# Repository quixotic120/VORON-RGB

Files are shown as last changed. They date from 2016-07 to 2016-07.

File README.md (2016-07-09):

# VORON-RGB

a fork to collect my changes to the Voron design. WIP at this point and untested but the changes are somewhat minor

##changes

increased volume - 300x300x300 (ish, lose some z axis as described below)

_bed supports_

modular steps updated to support anti-backlash delrin leadscrew nuts. For modded parts I've posted 123dx files and STLs. Also have an untested modification of the non-modular one if that's your thing.

_electronics_

currently using RADDS 1.5 w/ silentstepsticks but hopefully will be using my version of [RAMPS-FD](https://github.com/quixotic120/bobc_hardware/tree/master/RAMPS-FD)soon (once the kinks are worked out, on my git). Have modded the RADDS a bit with better headers and a converter for the RRD-graphic LCD

_color mixing hotend support_

added mount for the diamond hotend, different extruder design and 3 extruders for color mixing purposes (hopefully 5 soon for full color!). Kept it in line with the modular format used so it should be fairly easy to swap in a different hotend (I have an extra e3dv6-lite for this). 2 reasons: 1 being the diamond brings a lot of complexity so if it's not needed I prefer to avoid it and 2 being that the diamond is HUGE and you lose a bit of z axis as a result

extruder being used is [located here](https://github.com/quixotic120/printer-mods/tree/master/bowden)

_software_

using repetier instead of marlin for color mixing and due board support - untested but configuration should work?

_other_

using the excellent bed knobs by [bhstibal](http://www.thingiverse.com/thing:1645108)

considering using [hall effect endstops](https://github.com/quixotic120/hall-o)

using dc42s diff IR endstop instead of the inductive ones which kind of suck IMO. if you use the diff IR it is beneficial to paint the PEI black with high temp paint (like the kind of grills or engines)

using e3d pt-100 for hotends, using the e3d cartridge thermistor on the bed

adding a thermal fuse to the bed

##TODO:
Printer enclosure

RADDS enclosure - would like an enclosure that could hold RADDS, due, a pi zero for octoprint, and a header for powering accessories. Ideally in the style of the voron RAMPS enclosure

Camera mount

Filament Jam sensor and the possible modifications needed to firmware to make such a thing work with multiple filament extruders

#__original readme__

# VORON  


Reddit: [/r/voroncorexy](https://www.reddit.com/r/voroncorexy/)

Firmware, plans, and parts for VORON RepRap printer

## Updates:  

_Apr 30, 2016:_  
REV C Parts are pushed (STL and STEP). Parts included in this release:  
- Improved Bed Carriage  
- V1-to-REV C leadscrew adapter (for those who already printed v1)  
- Improved RAMPs Case  
- Improved Power Box (and mirror of v1 as default)  

_Apr 22, 2016:_  
Massive update to the manual. All motion system are done. Next is filamnt systems, and wiring. 
Also, added a BSP adapter for E3D Titan.

In other news, we have a sub-reddit now! Link at the top of the page.

_Apr 19, 2016:_  
Updated the BOM to reflect the REV B components. Link updated.

_Apr 17, 2016:_  
REV B Carriage is up. Belt tensioning every each way. I've cleaned up the folder to get rid of some older stuff nobody should be using now anyway.  
Description of changes here: http://imgur.com/a/EneHq

_Apr 15, 2016:_  
Quick update: The manual stalled out due to work on REV B of the X Carriage. At I started writing down the process, I became convinced belt tensioning is a thing that needs to happen. So I'm bringing back a version of what I had on the prototype printer. New carriage will also have a better way to mount a single E3D hot end, so you don't have to take apart X Carriage to remove it.

There are a few other special projects in the works, one of them involving E3D Titan ;)  

REV B will be going up tomorrow after I have a chance to put some more QA time on it.  

_Apr  4, 2016:_  
Updated BOM to reflect some changes discussed on GitHub. Big thanks to codexmas for QA work. Checked in a PDF version of the BOM. Manual is getting closer to being finished.

_Mar 22, 2016:_  
REV A STLs are published. Updated to the X Carriage to house a blower fan. Also updated the BOM to reflect the new configuration.

_Mar 8, 2016:_  
ver1.0 of the STLs has been released. Happy printing.

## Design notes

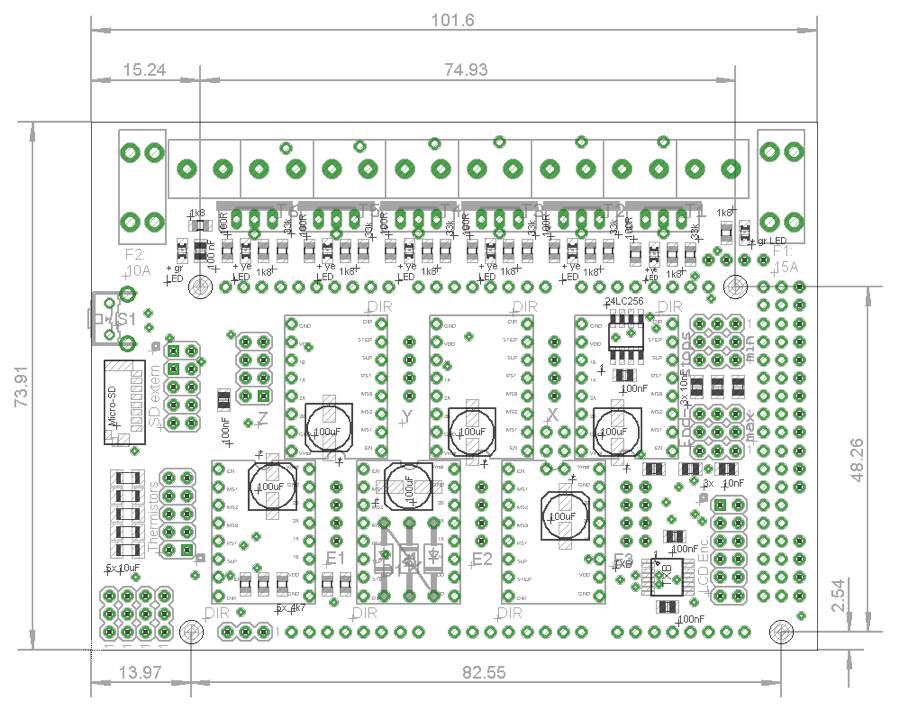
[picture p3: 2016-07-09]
RGB/WIP/RADDS_Case/Picture1.png

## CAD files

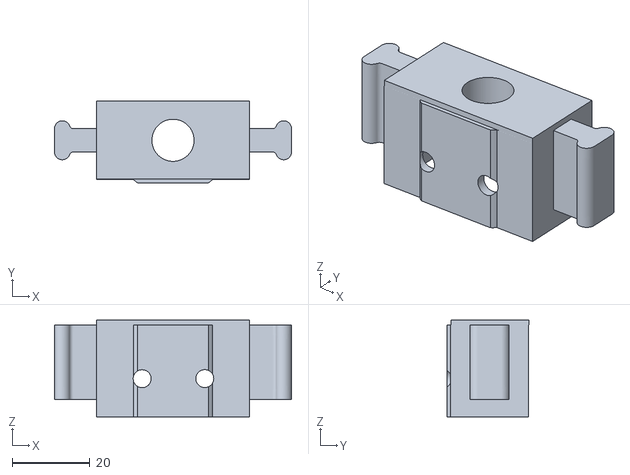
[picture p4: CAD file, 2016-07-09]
RGB/STL/BED C.stl
60.8 x 20.9 x 24.8

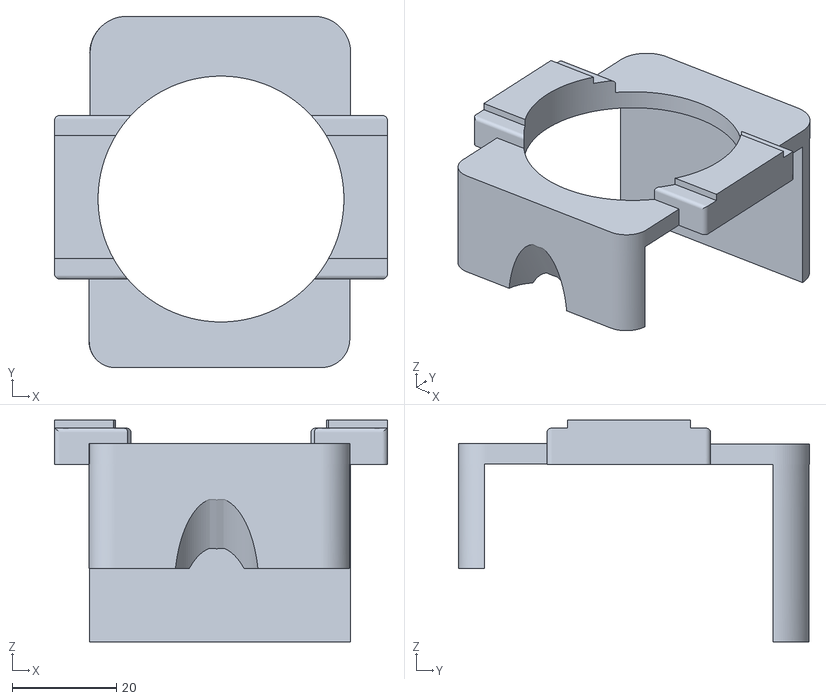
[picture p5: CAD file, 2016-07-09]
RGB/STL/x carriage lower.stl
63.9 x 67.4 x 42.5

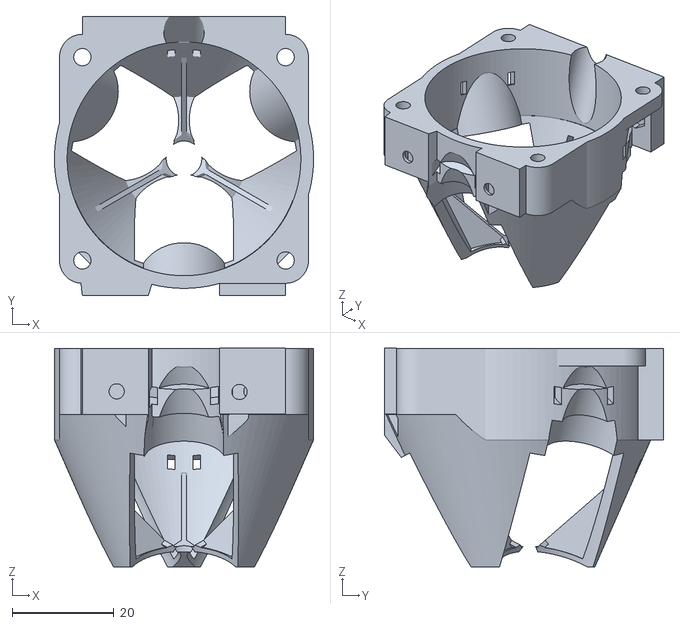
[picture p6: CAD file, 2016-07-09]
RGB/STL/diamond mount.stl
51.0 x 54.9 x 43.1

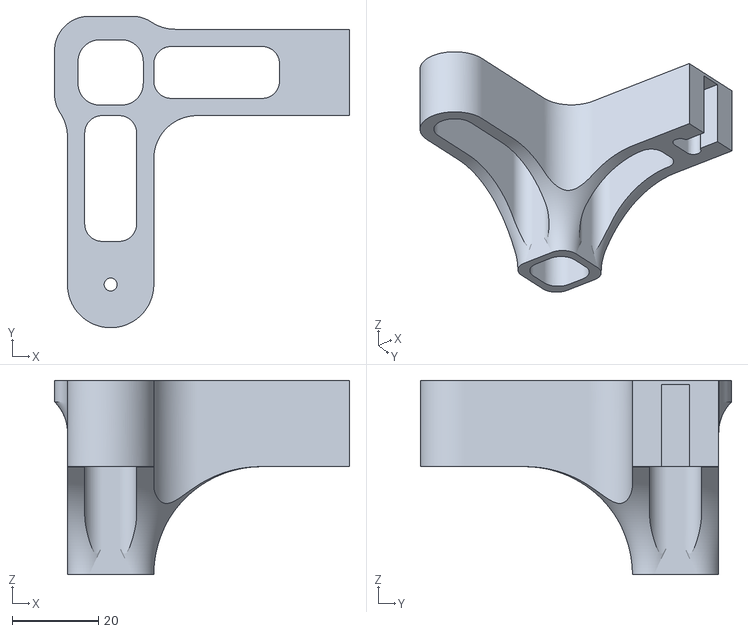
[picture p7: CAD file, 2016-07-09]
RGB/STL/BEDR.stl
68.3 x 72.1 x 45.0

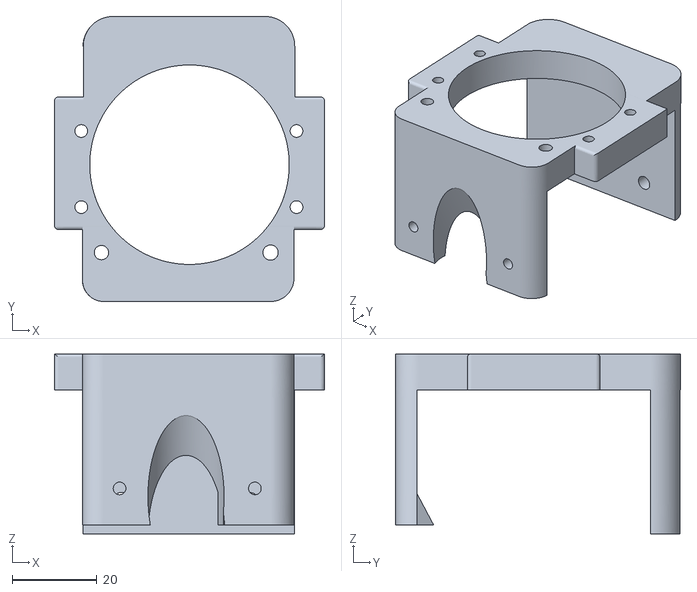
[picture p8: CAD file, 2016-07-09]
RGB/STL/x lower.stl
63.9 x 67.4 x 42.5

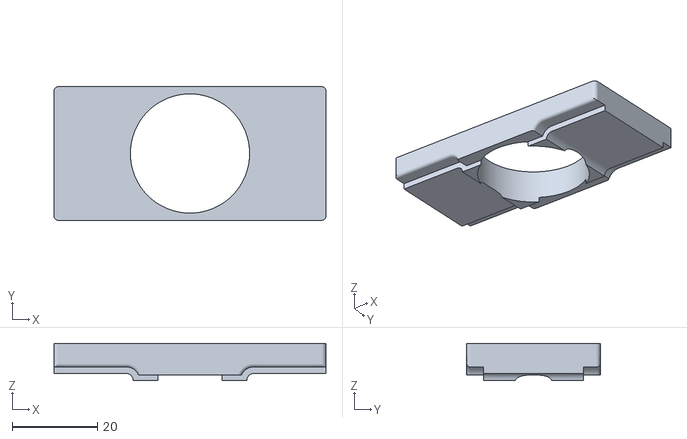
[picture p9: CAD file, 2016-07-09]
RGB/STL/x carriage upper.stl
63.9 x 31.4 x 8.70

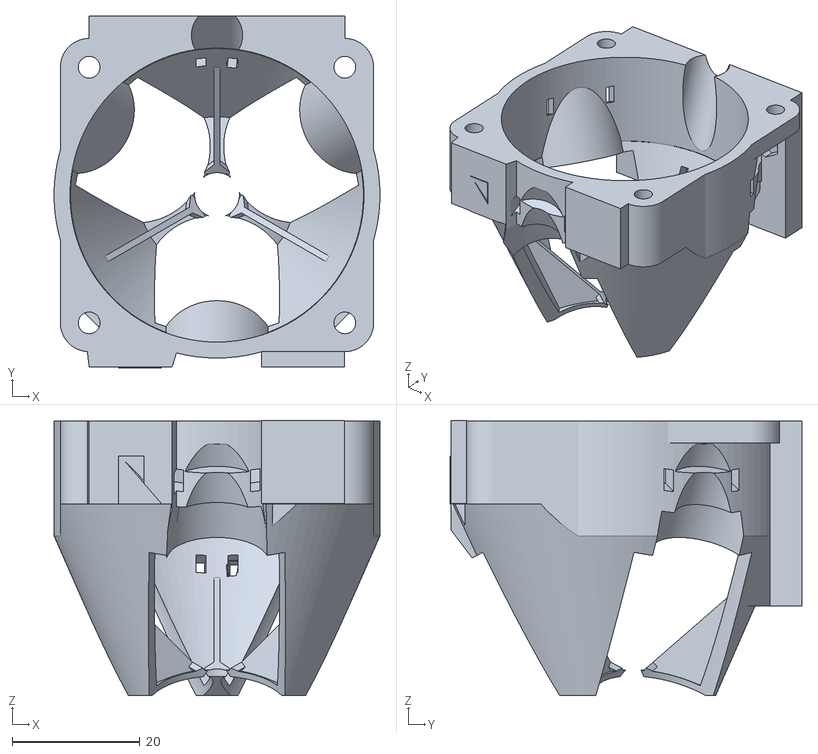
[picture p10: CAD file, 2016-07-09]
RGB/STL/updated diamond mount.stl
51.0 x 55.0 x 43.1

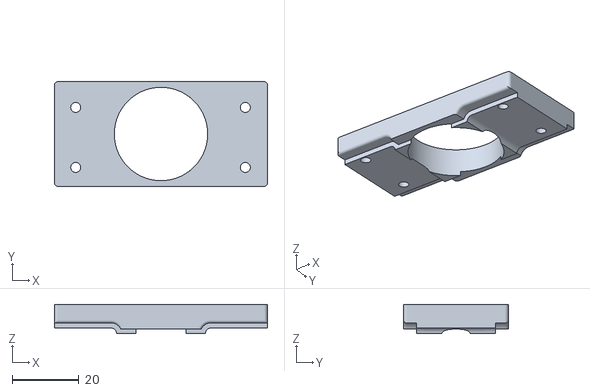
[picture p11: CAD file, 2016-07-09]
RGB/STL/x mount top.stl
63.9 x 31.4 x 8.70

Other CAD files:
RGB/STL/diamond w mount.stl
RGB/STL/BED L.stl

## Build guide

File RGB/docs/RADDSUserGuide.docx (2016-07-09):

# Wiring and configuration

## 1.1 Wiring diagram

### 1.1.1 Stepper drivers and motors

#### 1.1.1.1 Stepper motor

Before you can connect the stepper motor to RADDS or SilentStep , you need some information on the stepper motor you have.

Look at your motor, find its part number. Then Google it. Try to find a schematic or a data-sheet that will indicate which wire goes to which pole. Note the colors that correspond to each coil.

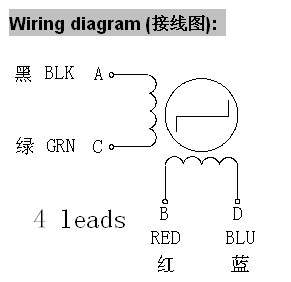
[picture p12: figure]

Wiring diagram for Wantai 42BYGHW609 stepper motor (from www.wantamotor.com).

If you can`t find the motor`s part number, you can use another method to find the motor`s pole pairs.
When two wires for a pole (A +C or B+D) touch together it makes a closed circuit for that pole and it gets harder to turn the stepper motor.

1. Try to turn the motor when no cables touch together – it should turn freely.
2. Touch two of the cables together – if the motor gets harder to turn, you have found a pole pair. If not, try to touch two other cables together until the motor gets harder to move.
3. When you have two cables together that makes it harder to turn the motor, you have found a pole pair.

Note the colors for each pole pair (Pair 1 = 1A +1B, Pair 2 = 2A+2B)



On the Wantai 42BYGHw609 the colors are:
1A = Black
1B = Green
2A = Blue
2B = Red

It does not matter if you swap the pole pairs. If the motor turns the wrong way, you can reverse it in the configuration file.

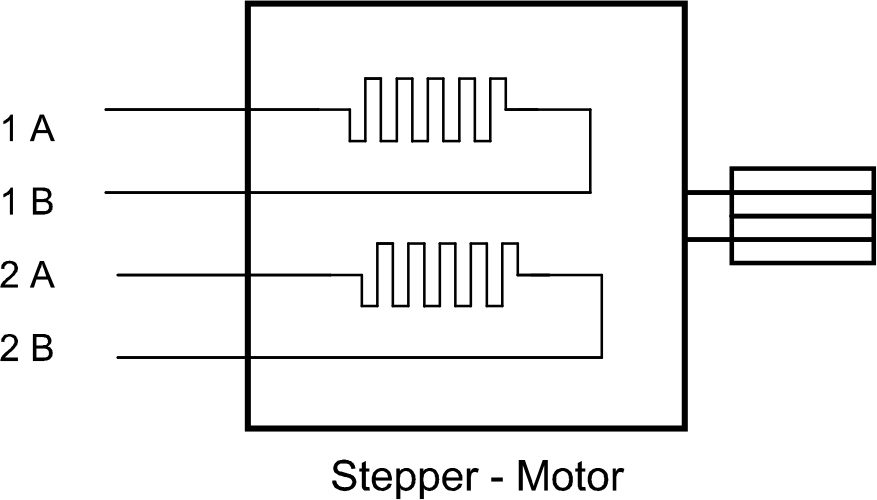
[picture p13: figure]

#### 1.1.1.2 Micro stepping

A stepper motor always has a fixed number of steps. Microstepping is a way of increasing the number of steps by sending a sine/cosine waveform to the coils inside the stepper motor. In most cases, micro stepping allows stepper motors to run smoother and more accurately.

Microstepping between pole-positions is made with lower torque than with full-stepping, but has much lower tendency for mechanical oscillation around the step-positions and you can drive with much higher frequencies.

If your motors are near to mechanical limitations and you have high friction or dynamics, microsteps do not give you much more accuracy over half-stepping. When your motors are 'overpowered' and/or you do not have much friction, then microstepping can give you much higher accuracy over half-stepping. You can transfer the higher positioning accuracy to moving accuracy too

Source: http://www.reprap.org/wiki/Stepper_motor#Micro_stepping

If you want to alter the micro stepping value on one or more axis, you have to set the correct value. When using SilentStep , you set it using the dipswitches on the SilentStep and modify the values in the configuration.h file

Each time you increase the stepping one level (sample: from 1/16 to 1/32) you have to multiply the steps per unit value by two.

Sample – You are using 1/16 steps per unit and the value is 80 and want to use 1/32 steps per unit.

If your steps per unit value is 80, you have to multiply 80 by two (2x80).

New steps per unit value = 160

// #define DEFAULT_AXIS_STEPS_PER_UNIT {78.7402,78.7402,200.0*8/3,760*1.1} // default steps per unit for Ultimaker

//#define DEFAULT_AXIS_STEPS_PER_UNIT {80,80,2560,107} // default steps per unit for OrdBot 1/16

#define DEFAULT_AXIS_STEPS_PER_UNIT {160,160,5120,214} // default steps per unit for OrdBot 1/32

This code sample is from Marlin.

The “default steps per unit for OrdBot 1/16” gives you the values for 1/16 micro stepping.

80, 80, 2560, 107
X-Axis = 80 steps/mm
Y-Axis = 80 steps/mm
Z-Axis = 2560 steps/mm
Extruder motor = 107 steps/mm (this is the setting for Bulldog Lite Extruder. You have to find the correct setting for the extruder you use)

In the next code line, you find “default steps per unit for OrdBot 1/32”. This is the settings when 1/32 microstepping are used. Here all values have been multiplied with two.

#### 1.1.1.3 Set the micro stepping mode on RADDS 1.1

When you use stepper drivers like the A4988, DRV8825 (NOT WHEN USING EXTERNAL DRIVERS LIKE SILENTSTEP ) you have to set the micro stepping mode by cutting or connecting the traces on the back of the RADDS board.

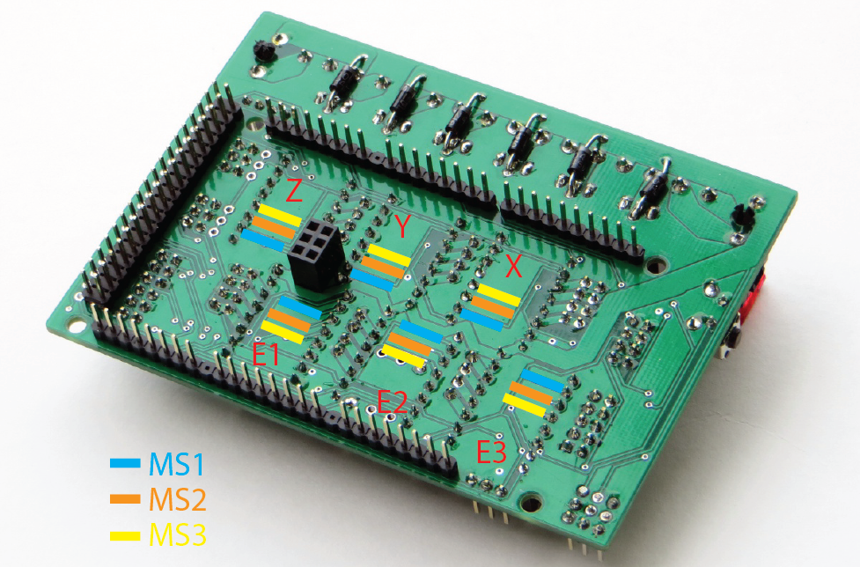
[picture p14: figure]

A4988 | | | DRV8825 | | | RAPS128
MS1 | MS2 | MS3 | MS1 | MS2 | MS3 | MS1 | MS2 | MS3 | STEP
L | L | L | L | L | L | L | L | L | 1
H | L | L | H | L | L | H | L | L | 1/2
L | H | L | L | H | L | L | H | L | 1/4
H | H | L | H | H | L | H | H | L | 1/8
H | H | H | L | L | H | L | L | H | 1/16
| | | H | H | H | H | L | H | 1/32
| | | | | | L | H | H | 1/64
| | | | | | H | H | H | 1/128

In this image, the traces have different colors to make it easier to find the correct traces.

In the table, you find the different stepping modes for the most used drivers.
L = Open trace, H = Closed trace (MS pin = 3,3V = default)
When using the DRV8825 the combinations HLH, LHH and HHH all gives 1/32 STEP

IMPORTANT you have to set the same stepping mode in the configuration.h file and update the controller software.

#### 1.1.1.4 1Mounting stepper drivers like A4988, DRV8825 or stepper driver adapters

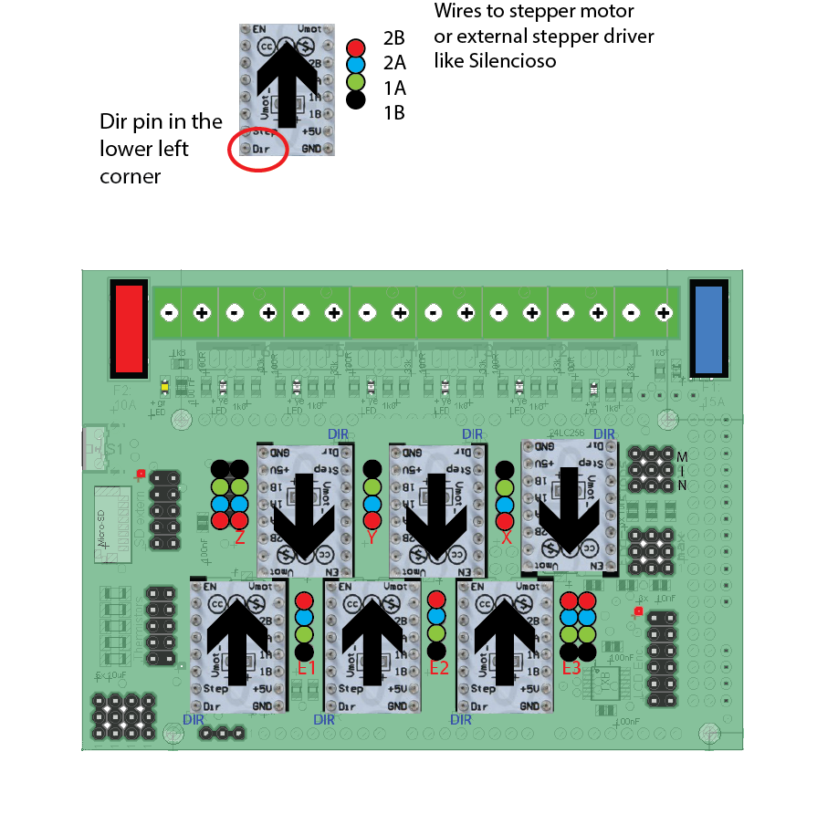
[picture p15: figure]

SilentStep stepper driver adapters used as a sample in this wiring diagram, but the other drivers have the same pin labels.

Insert the stepper drivers/adapters (X, Y and Z) with the DIR pin in the upper right corner (upside down)

Insert the stepper drivers/adapters (E1, E2 and E3) with the DIR pin in the lower left corner.

The X, Y and Z motor cables have the black wire at the top

The E1, E2 and E3 wires have the red wire at the top

The Z and E3 have dual motor cable connections so you can connect two motors.

#### 1.1.1.5 Normal setup when using external stepper drivers like RRD SilentStep

This is the normal way to connect a SilentStep driver and motor.

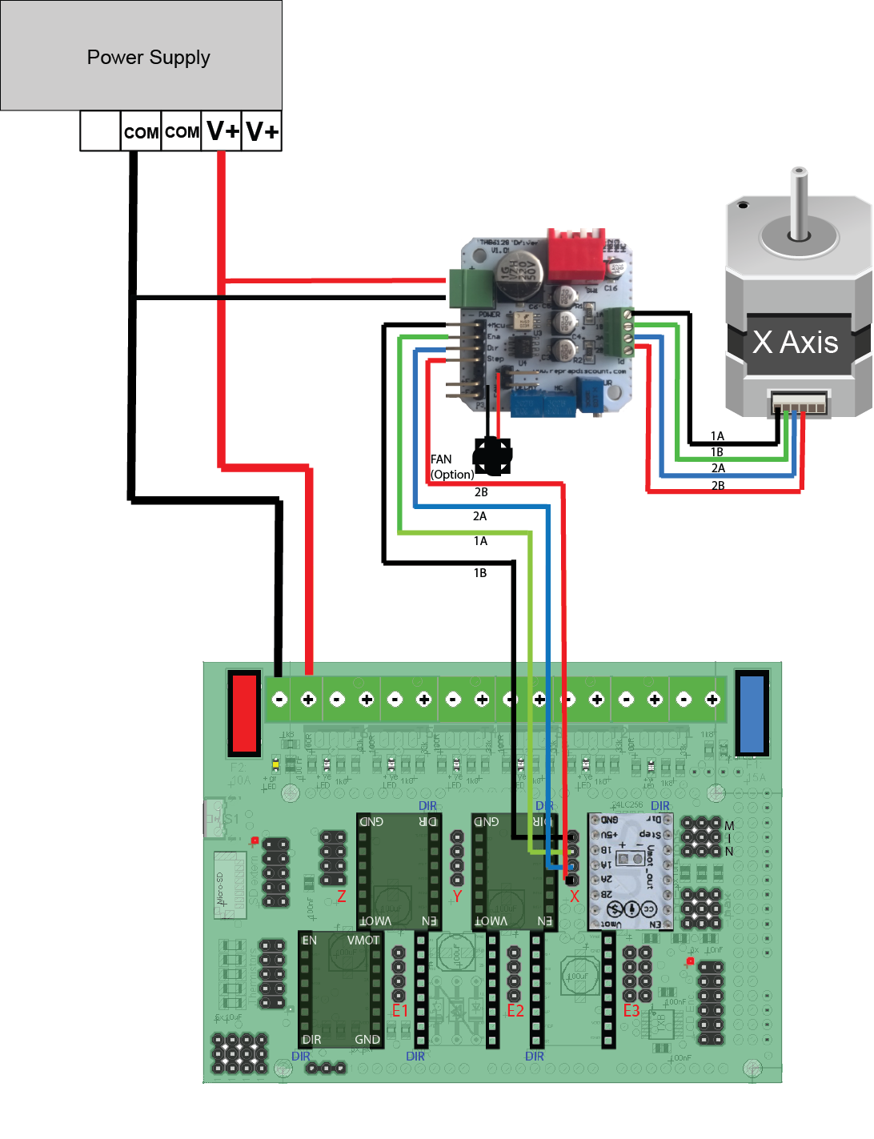
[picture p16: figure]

#### 1.1.1.6 Dual Z stepper motor alternative 1 (dual SilentStep s)

Use this setup when the total current used by the two motors exceeds the current limit of one SilentStep

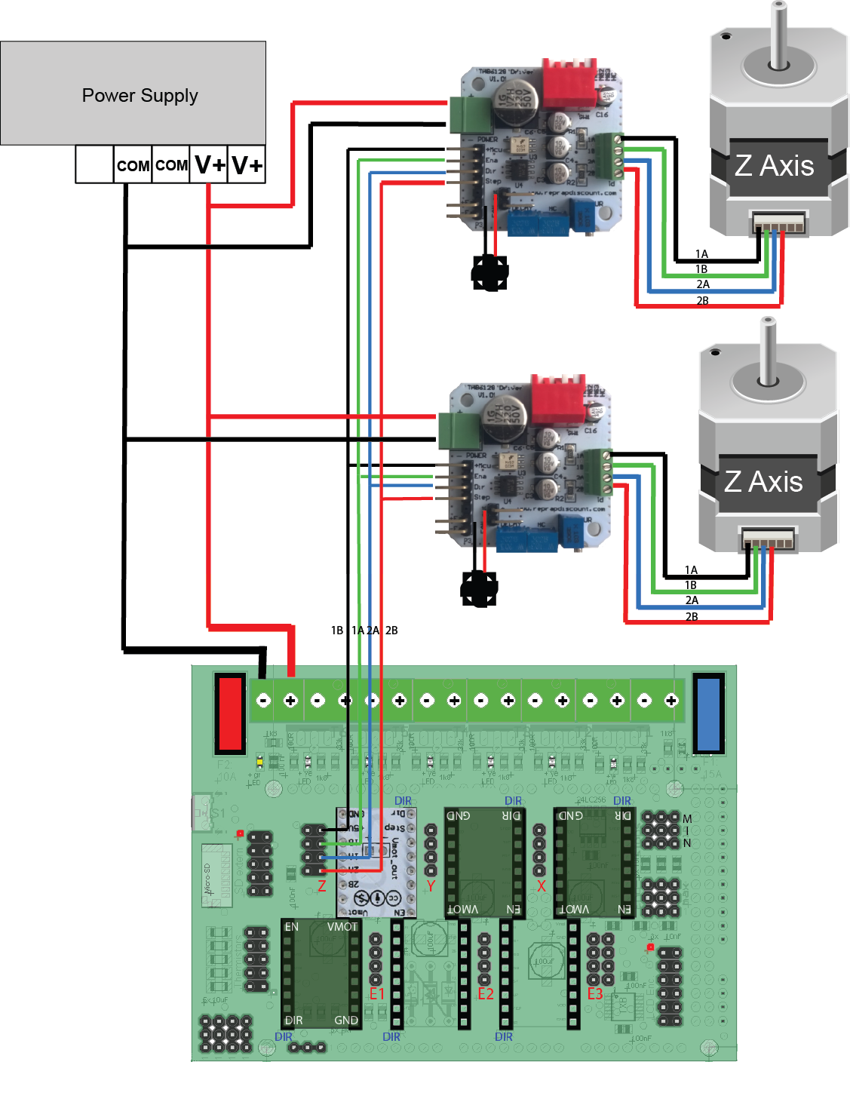
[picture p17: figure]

#### 1.1.1.7 Dual Z stepper motor alternative 2

This is an option if the total current used by the two stepper motors are lower than the SilentStep max current limit.

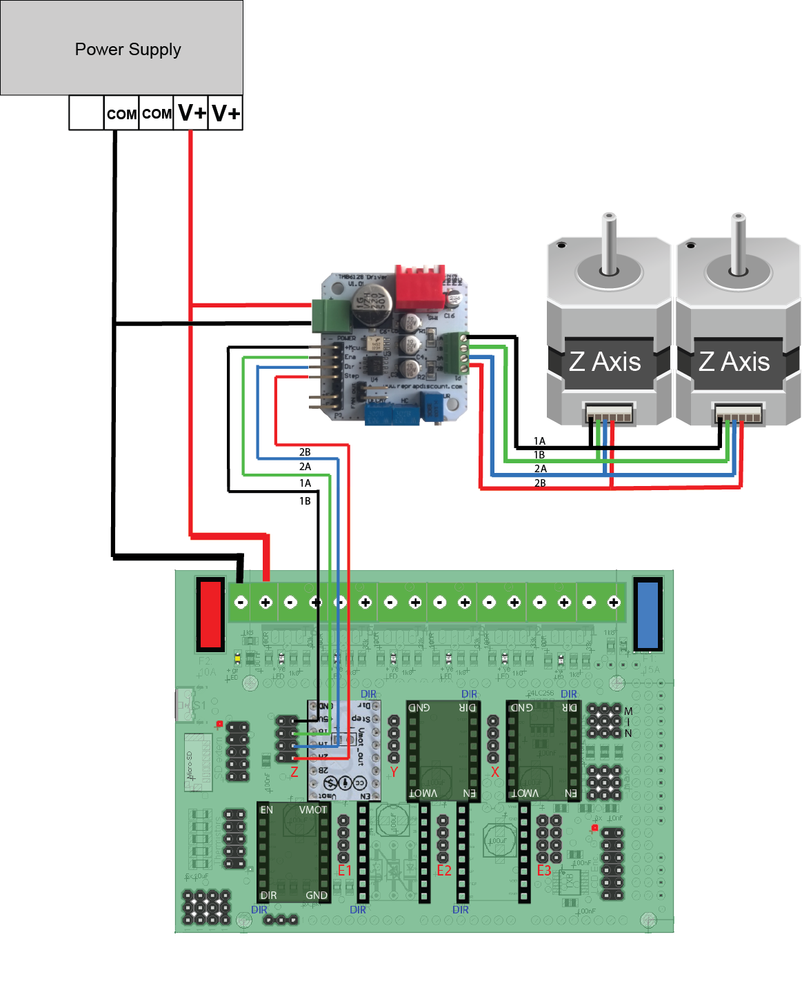
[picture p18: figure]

### 1.1.2 RADDS + Endstops

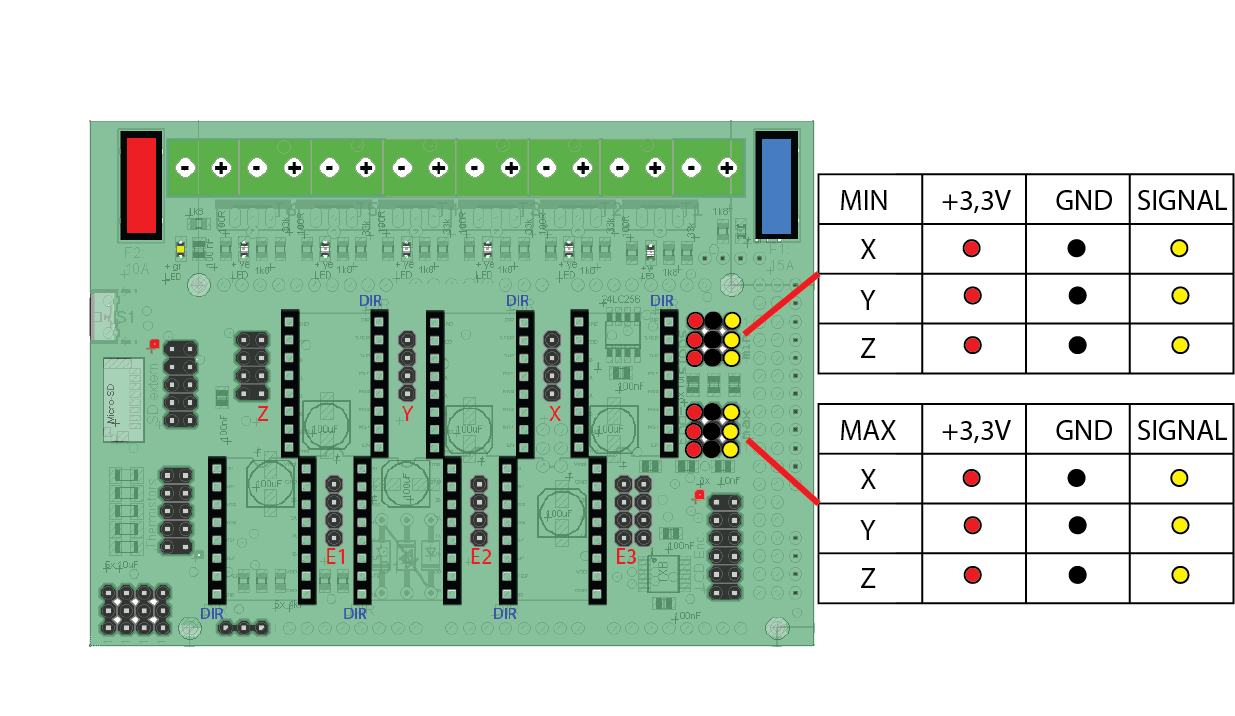
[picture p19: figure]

As default there is no pins soldered in the +3.3V as they`re not needed when using mechanical endstops.

Mechanical endstops:
Connect the mechanical endstops to the GND and Signal pins so they are normally closed (push = open)

Hal-O endstops (magnetic):
When using the Hal-O endstops you have to connect the + pin on the Hal-O to the +5V pin.

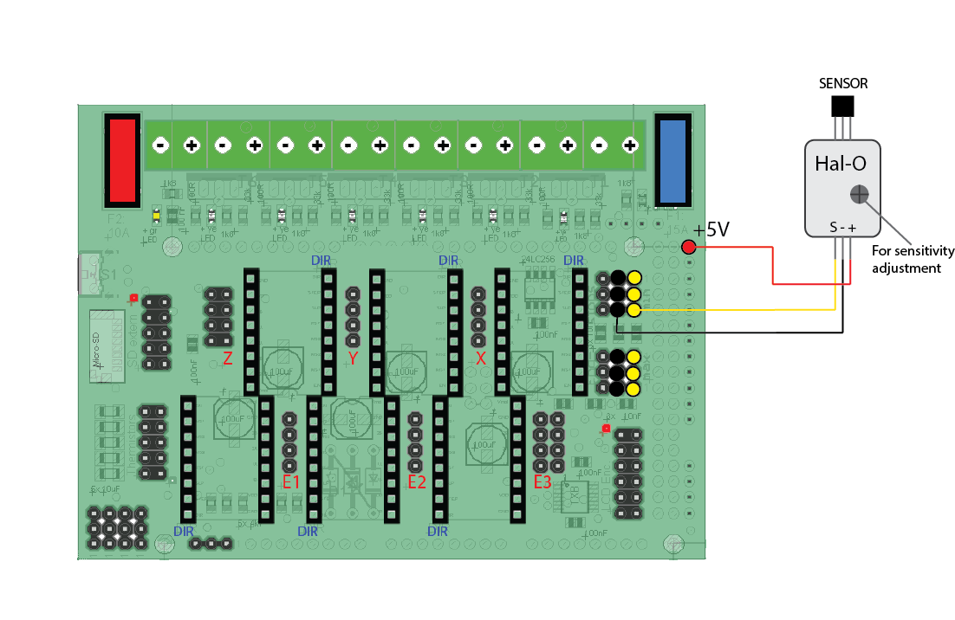
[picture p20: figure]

IMPORTANT!!
When using electronic endstops like the Hal-O, only use endstop that have max 3.3V out on the signal pin

### 1.1.3 RADDS OrdBot Wiring diagram

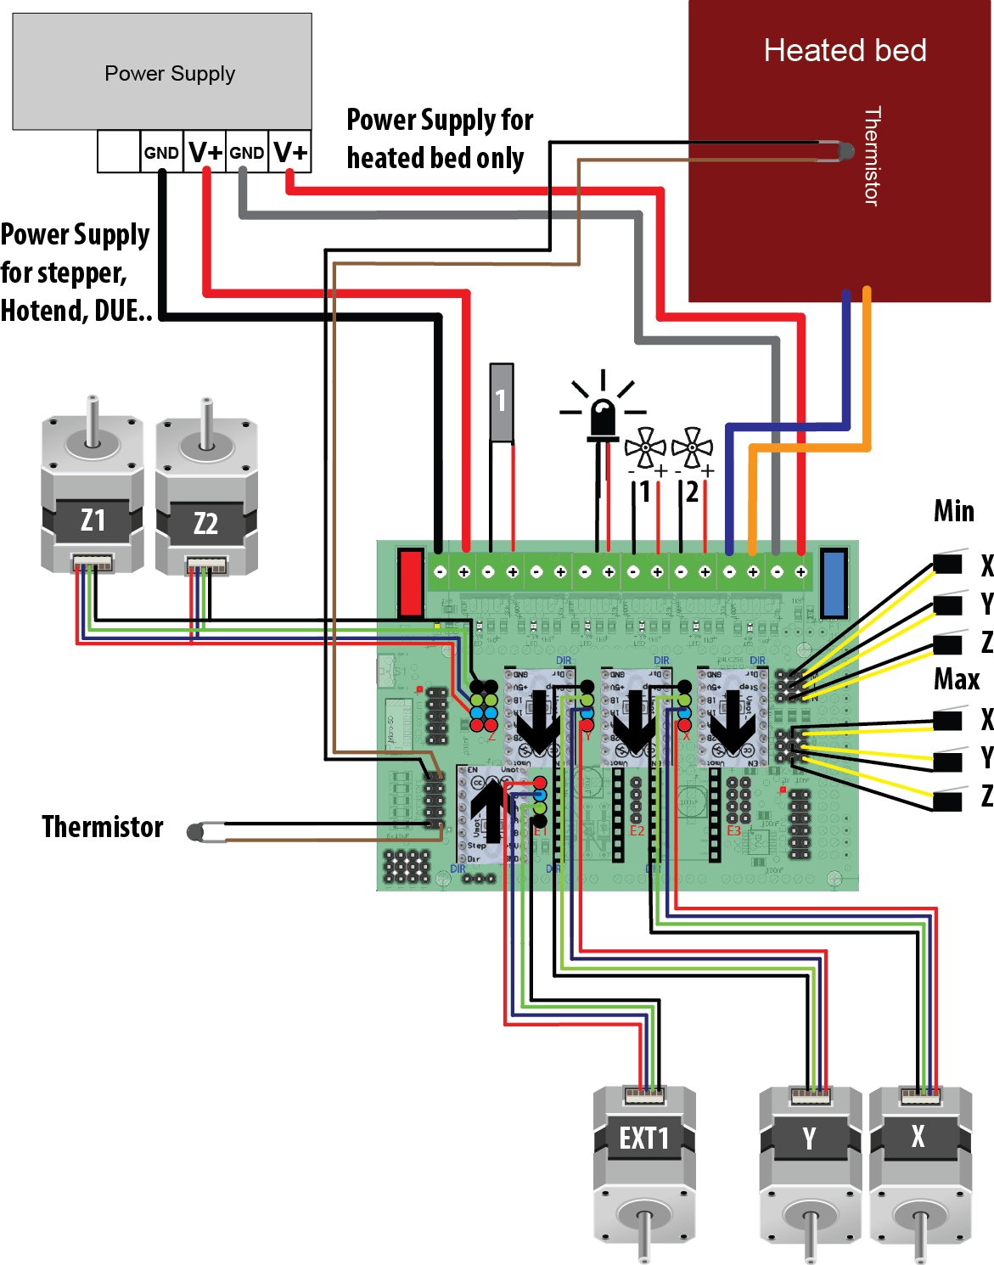
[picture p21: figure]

### 1.1.4 Installation

- Upgrade the stepper motors with SilentStep stepper drivers (separate user guide)
- Connect the RADDS shield onto the Arduino DUE board
- Install the SilentStep stepper driver adapters (X, Y, Z and EXT1). Make sure the orientation is correct.
- Connect the RADDS LCD control panel
- Connect the stepper motors. In this sample dual SilentStep s are used for the dual Z stepper motors (2.1.4.3)
- Connect extruder motor to EXT1
- Connect the hotend heater element to heater element output 1
- Connect the hotend thermistor to thermistor input 1
- Connect the hotend Fan to Fan 1 output
- Connect the filament Fan to Fan 2 output
- Connect the 12V LED strip to heater output 3
- Connect HeatedBed thermistor to thermistor input 4
- Connect HeatedBed 12V to the HeatedBed 12V output
- Connect 12V from PSU to heated bed power input (right side)
- Connect the main power input from the PSU to 12V input (left side)
- Connect the USB cable to the programming port (the one in the lower left corner on the DUE)

IMPORTANT – before you power on your printer for the first time, you must finish the software setup.

Make sure all wiring is correct. If you have connected something the wrong way, you may damage your electronics.

USER GUIDE

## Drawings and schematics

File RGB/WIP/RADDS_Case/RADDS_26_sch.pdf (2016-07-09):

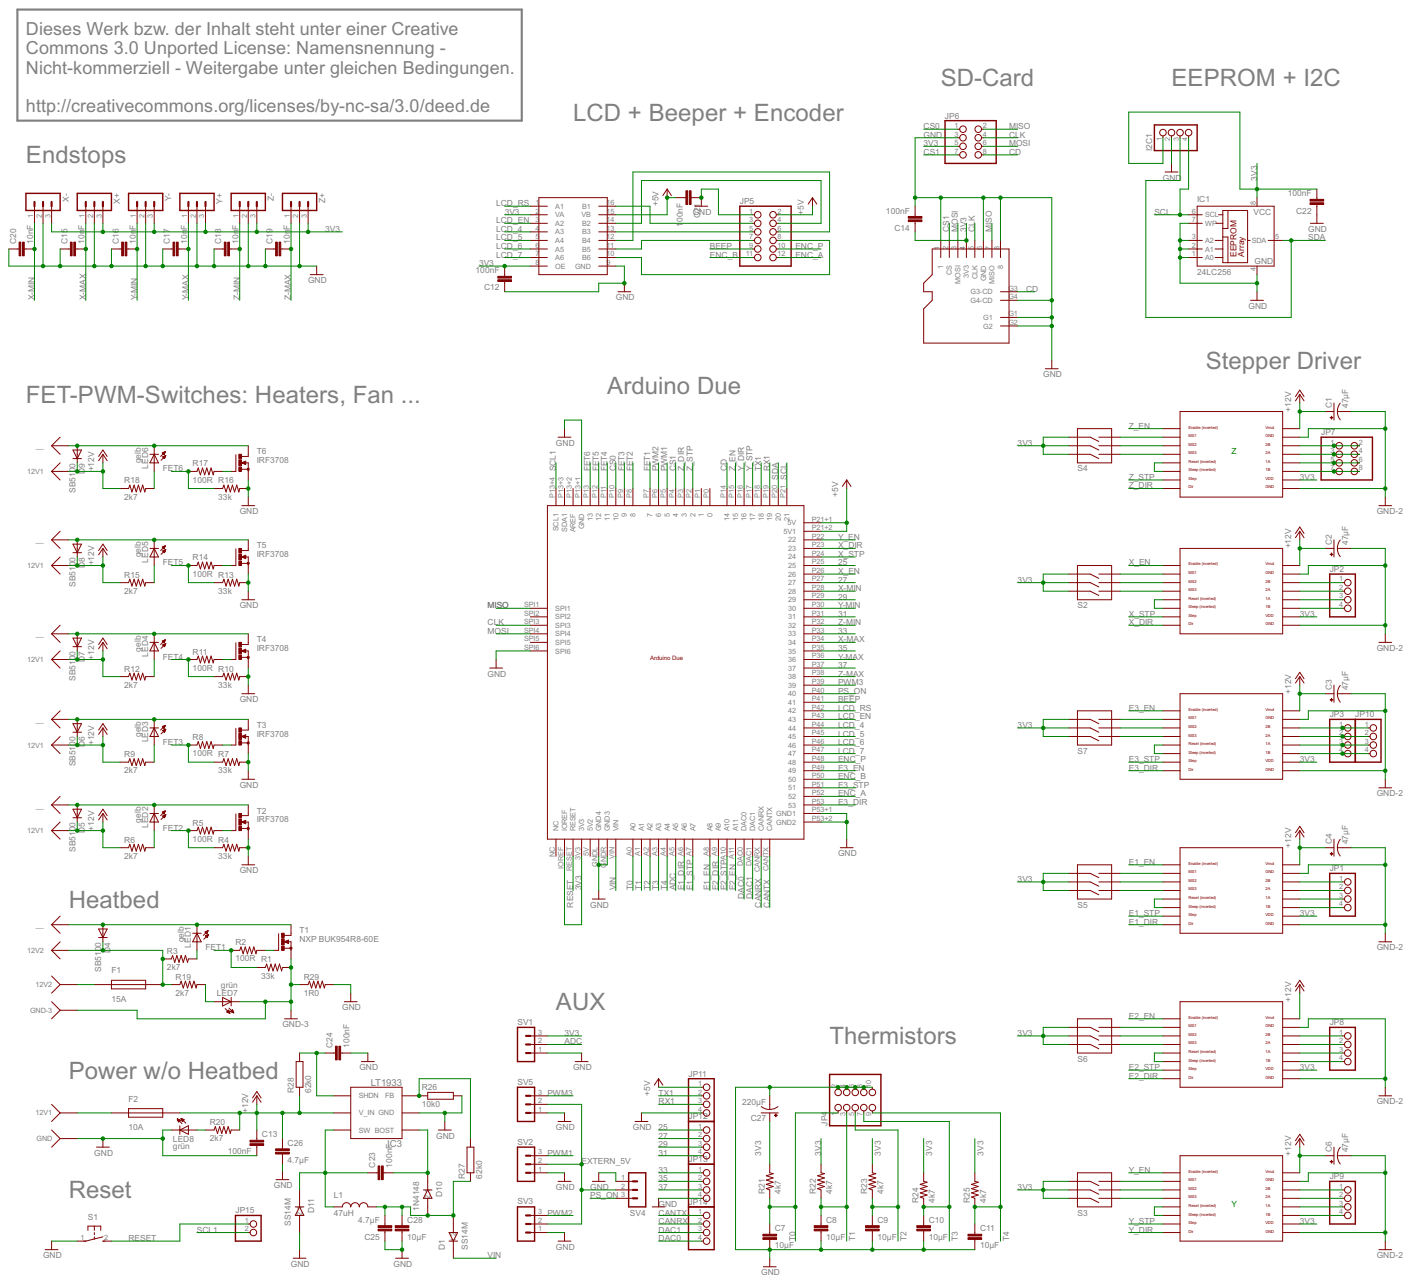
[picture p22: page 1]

Dieses Werk bzw. der Inhalt steht unter einer Creative Commons 3.0 Unported License: Namensnennung - Nicht-kommerziell - Weitergabe unter gleichen Bedingungen. http://creativecommons.org/licenses/by-nc-sa/3.0/deed.de

13 B4 | | 7 8
12 B5 11 B6 BEEP | 9 10 | ENC_P

FET-PWM-Switches: Heaters, Fan ...

CANRX CANRX CANTX CANTX DAC0 DAC0 DAC1 DAC1

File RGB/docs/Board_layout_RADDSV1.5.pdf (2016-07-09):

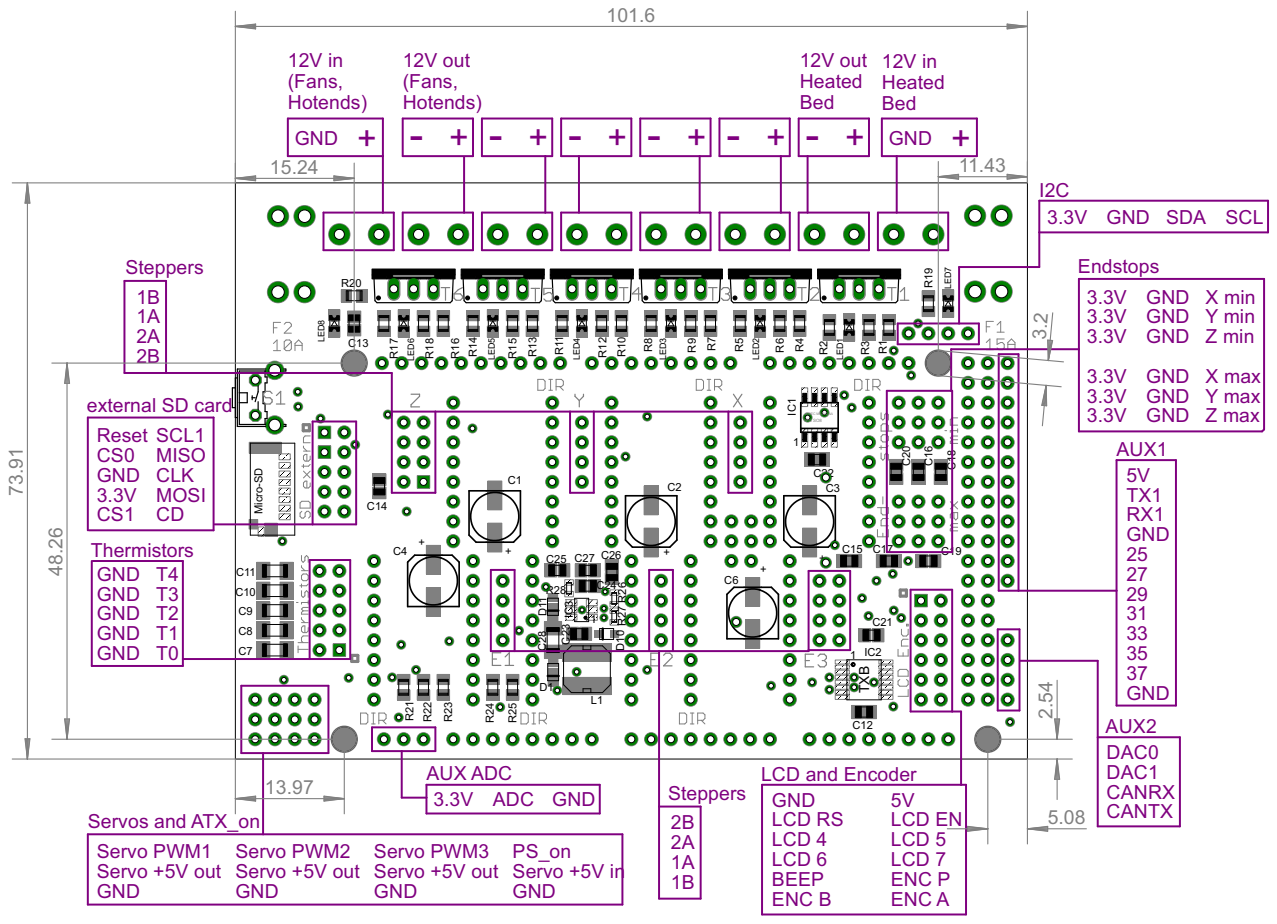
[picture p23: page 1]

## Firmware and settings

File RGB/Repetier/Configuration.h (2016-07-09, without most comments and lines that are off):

#define CONFIGURATION_H
#define NUM_EXTRUDER 3
#define MOTHERBOARD 402
#define RFSERIAL Serial
#include "pins.h"
#undef FAN_BOARD_PIN
#define FAN_BOARD_PIN -1
#define BOARD_FAN_SPEED 255
#define FAN_THERMO_PIN -1
#define FAN_THERMO_MIN_PWM 128
#define FAN_THERMO_MAX_PWM 255
#define FAN_THERMO_MIN_TEMP 45
#define FAN_THERMO_MAX_TEMP 60
#define FAN_THERMO_THERMISTOR_PIN -1
#define FAN_THERMO_THERMISTOR_TYPE 1
#define BLUETOOTH_SERIAL  -1
#define BLUETOOTH_BAUD  115200
#define MIXING_EXTRUDER 1
#define DRIVE_SYSTEM 2
#define XAXIS_STEPS_PER_MM 79.71
#define YAXIS_STEPS_PER_MM 78.22
#define ZAXIS_STEPS_PER_MM 2589.08
#define EXTRUDER_FAN_COOL_TEMP 30
#define PDM_FOR_EXTRUDER 0
#define PDM_FOR_COOLER 0
#define DECOUPLING_TEST_MAX_HOLD_VARIANCE 40
#define DECOUPLING_TEST_MIN_TEMP_RISE 1
#define KILL_IF_SENSOR_DEFECT 1
#define RETRACT_ON_PAUSE 2
#define PAUSE_START_COMMANDS ""
#define PAUSE_END_COMMANDS ""
#define SHARED_EXTRUDER_HEATER 1
#define EXT0_X_OFFSET 0
#define EXT0_Y_OFFSET 0
#define EXT0_Z_OFFSET 0
#define EXT0_STEPS_PER_MM 370
#define EXT0_TEMPSENSOR_TYPE 13
#define EXT0_TEMPSENSOR_PIN TEMP_0_PIN
#define EXT0_HEATER_PIN HEATER_0_PIN
#define EXT0_STEP_PIN ORIG_E0_STEP_PIN
#define EXT0_DIR_PIN ORIG_E0_DIR_PIN
#define EXT0_INVERSE 0
#define EXT0_ENABLE_PIN ORIG_E0_ENABLE_PIN
#define EXT0_ENABLE_ON 0
#define EXT0_MIRROR_STEPPER 0
#define EXT0_STEP2_PIN ORIG_E0_STEP_PIN
#define EXT0_DIR2_PIN ORIG_E0_DIR_PIN
#define EXT0_INVERSE2 0
#define EXT0_ENABLE2_PIN ORIG_E0_ENABLE_PIN
#define EXT0_MAX_FEEDRATE 50
#define EXT0_MAX_START_FEEDRATE 20
#define EXT0_MAX_ACCELERATION 5000
#define EXT0_HEAT_MANAGER 1
#define EXT0_WATCHPERIOD 1
#define EXT0_PID_INTEGRAL_DRIVE_MAX 255
#define EXT0_PID_INTEGRAL_DRIVE_MIN 40
#define EXT0_PID_PGAIN_OR_DEAD_TIME 7
#define EXT0_PID_I 2
#define EXT0_PID_D 40
#define EXT0_PID_MAX 255
#define EXT0_ADVANCE_K 0
#define EXT0_ADVANCE_L 0
#define EXT0_ADVANCE_BACKLASH_STEPS 0
#define EXT0_WAIT_RETRACT_TEMP 175
#define EXT0_WAIT_RETRACT_UNITS 3
#define EXT0_SELECT_COMMANDS ""
#define EXT0_DESELECT_COMMANDS ""
#define EXT0_EXTRUDER_COOLER_PIN -1
#define EXT0_EXTRUDER_COOLER_SPEED 255
#define EXT0_DECOUPLE_TEST_PERIOD 12000
#define EXT0_JAM_PIN -1
#define EXT0_JAM_PULLUP 0
#define EXT1_X_OFFSET 0
#define EXT1_Y_OFFSET 0
#define EXT1_Z_OFFSET 0
#define EXT1_STEPS_PER_MM 370
#define EXT1_TEMPSENSOR_TYPE 1
#define EXT1_TEMPSENSOR_PIN TEMP_2_PIN
#define EXT1_HEATER_PIN HEATER_2_PIN
#define EXT1_STEP_PIN ORIG_E1_STEP_PIN
#define EXT1_DIR_PIN ORIG_E1_DIR_PIN
#define EXT1_INVERSE 0
#define EXT1_ENABLE_PIN ORIG_E1_ENABLE_PIN
#define EXT1_ENABLE_ON 0
#define EXT1_MIRROR_STEPPER 0
#define EXT1_STEP2_PIN ORIG_E1_STEP_PIN
#define EXT1_DIR2_PIN ORIG_E1_DIR_PIN
#define EXT1_INVERSE2 0
#define EXT1_ENABLE2_PIN ORIG_E1_ENABLE_PIN
#define EXT1_MAX_FEEDRATE 50
#define EXT1_MAX_START_FEEDRATE 20
#define EXT1_MAX_ACCELERATION 5000
#define EXT1_HEAT_MANAGER 3
#define EXT1_WATCHPERIOD 1
#define EXT1_PID_INTEGRAL_DRIVE_MAX 230
#define EXT1_PID_INTEGRAL_DRIVE_MIN 40
#define EXT1_PID_PGAIN_OR_DEAD_TIME 7
#define EXT1_PID_I 2
#define EXT1_PID_D 40
#define EXT1_PID_MAX 255
#define EXT1_ADVANCE_K 0
#define EXT1_ADVANCE_L 0
#define EXT1_ADVANCE_BACKLASH_STEPS 0
#define EXT1_WAIT_RETRACT_TEMP 150
#define EXT1_WAIT_RETRACT_UNITS 0
#define EXT1_SELECT_COMMANDS ""
#define EXT1_DESELECT_COMMANDS ""
#define EXT1_EXTRUDER_COOLER_PIN -1
#define EXT1_EXTRUDER_COOLER_SPEED 255
#define EXT1_DECOUPLE_TEST_PERIOD 12000
#define EXT1_JAM_PIN -1
#define EXT1_JAM_PULLUP 0
#define EXT2_X_OFFSET 0
#define EXT2_Y_OFFSET 0
#define EXT2_Z_OFFSET 0
#define EXT2_STEPS_PER_MM 370
#define EXT2_TEMPSENSOR_TYPE 1
#define EXT2_TEMPSENSOR_PIN TEMP_3_PIN
#define EXT2_HEATER_PIN HEATER_3_PIN
#define EXT2_STEP_PIN ORIG_E2_STEP_PIN
#define EXT2_DIR_PIN ORIG_E2_DIR_PIN
#define EXT2_INVERSE 0
#define EXT2_ENABLE_PIN ORIG_E2_ENABLE_PIN
#define EXT2_ENABLE_ON 0
#define EXT2_MIRROR_STEPPER 0
#define EXT2_STEP2_PIN ORIG_E2_STEP_PIN
#define EXT2_DIR2_PIN ORIG_E2_DIR_PIN
#define EXT2_INVERSE2 0
#define EXT2_ENABLE2_PIN ORIG_E2_ENABLE_PIN
#define EXT2_MAX_FEEDRATE 50
#define EXT2_MAX_START_FEEDRATE 20
#define EXT2_MAX_ACCELERATION 5000
#define EXT2_HEAT_MANAGER 3
#define EXT2_WATCHPERIOD 1
#define EXT2_PID_INTEGRAL_DRIVE_MAX 230
#define EXT2_PID_INTEGRAL_DRIVE_MIN 40
#define EXT2_PID_PGAIN_OR_DEAD_TIME 7
#define EXT2_PID_I 2
#define EXT2_PID_D 40
#define EXT2_PID_MAX 255
#define EXT2_ADVANCE_K 0
#define EXT2_ADVANCE_L 0
#define EXT2_ADVANCE_BACKLASH_STEPS 0
#define EXT2_WAIT_RETRACT_TEMP 150
#define EXT2_WAIT_RETRACT_UNITS 0
#define EXT2_SELECT_COMMANDS ""
#define EXT2_DESELECT_COMMANDS ""
#define EXT2_EXTRUDER_COOLER_PIN -1
#define EXT2_EXTRUDER_COOLER_SPEED 255
#define EXT2_DECOUPLE_TEST_PERIOD 12000
#define EXT2_JAM_PIN -1
#define EXT2_JAM_PULLUP 0
#define FEATURE_RETRACTION 1
#define AUTORETRACT_ENABLED 0
#define RETRACTION_LENGTH 3
#define RETRACTION_LONG_LENGTH 13
#define RETRACTION_SPEED 40
#define RETRACTION_Z_LIFT 0
#define RETRACTION_UNDO_EXTRA_LENGTH 0
#define RETRACTION_UNDO_EXTRA_LONG_LENGTH 0
#define RETRACTION_UNDO_SPEED 20
#define FILAMENTCHANGE_X_POS 0
#define FILAMENTCHANGE_Y_POS 0
#define FILAMENTCHANGE_Z_ADD  2
#define FILAMENTCHANGE_REHOME 1
#define FILAMENTCHANGE_SHORTRETRACT 5
#define FILAMENTCHANGE_LONGRETRACT 50
#define JAM_STEPS 220
#define JAM_SLOWDOWN_STEPS 320
#define JAM_SLOWDOWN_TO 70
#define JAM_ERROR_STEPS 500
#define JAM_MIN_STEPS 10
#define JAM_ACTION 1
#define RETRACT_DURING_HEATUP true
#define PID_CONTROL_RANGE 20
#define SKIP_M109_IF_WITHIN 2
#define SCALE_PID_TO_MAX 0
#define TEMP_HYSTERESIS 5
#define EXTRUDE_MAXLENGTH 160
#define NUM_TEMPS_USERTHERMISTOR0 0
#define USER_THERMISTORTABLE0 {}
#define NUM_TEMPS_USERTHERMISTOR1 0
#define USER_THERMISTORTABLE1 {}
#define NUM_TEMPS_USERTHERMISTOR2 0
#define USER_THERMISTORTABLE2 {}
#define GENERIC_THERM_VREF 5
#define GENERIC_THERM_NUM_ENTRIES 33
#define HEATER_PWM_SPEED 0
#define HAVE_HEATED_BED 1
#define HEATED_BED_MAX_TEMP 130
#define SKIP_M190_IF_WITHIN 5
#define HEATED_BED_SENSOR_TYPE 8
#define HEATED_BED_SENSOR_PIN TEMP_1_PIN
#define HEATED_BED_HEATER_PIN HEATER_1_PIN
#define HEATED_BED_SET_INTERVAL 5000
#define HEATED_BED_HEAT_MANAGER 1
#define HEATED_BED_PID_INTEGRAL_DRIVE_MAX 255
#define HEATED_BED_PID_INTEGRAL_DRIVE_MIN 40
#define HEATED_BED_PID_PGAIN_OR_DEAD_TIME   196
#define HEATED_BED_PID_IGAIN   33
#define HEATED_BED_PID_DGAIN 290
#define HEATED_BED_PID_MAX 255
#define HEATED_BED_DECOUPLE_TEST_PERIOD 300000
#define MIN_EXTRUDER_TEMP 160
#define MAXTEMP 280
#define MIN_DEFECT_TEMPERATURE 0
#define MAX_DEFECT_TEMPERATURE 290
#define SUPPORT_LASER 0
#define LASER_PIN -1
#define LASER_ON_HIGH 1
#define SUPPORT_CNC 0
#define CNC_WAIT_ON_ENABLE 300
#define CNC_WAIT_ON_DISABLE 0
#define CNC_ENABLE_PIN -1
#define CNC_ENABLE_WITH 1
#define CNC_DIRECTION_PIN -1
#define CNC_DIRECTION_CW 1
#define DEFAULT_PRINTER_MODE 0
#define ENDSTOP_PULLUP_X_MIN true
#define ENDSTOP_X_MIN_INVERTING true
#define MIN_HARDWARE_ENDSTOP_X true
#define ENDSTOP_PULLUP_Y_MIN true
#define ENDSTOP_Y_MIN_INVERTING true
#define MIN_HARDWARE_ENDSTOP_Y true
#define ENDSTOP_PULLUP_Z_MIN true
#define ENDSTOP_Z_MIN_INVERTING true
#define MIN_HARDWARE_ENDSTOP_Z true
#define ENDSTOP_PULLUP_X_MAX true
#define ENDSTOP_X_MAX_INVERTING false
#define MAX_HARDWARE_ENDSTOP_X false
#define ENDSTOP_PULLUP_Y_MAX true
#define ENDSTOP_Y_MAX_INVERTING false
#define MAX_HARDWARE_ENDSTOP_Y false
#define ENDSTOP_PULLUP_Z_MAX true
#define ENDSTOP_Z_MAX_INVERTING false
#define MAX_HARDWARE_ENDSTOP_Z false
#define max_software_endstop_r true
#define min_software_endstop_x false
#define min_software_endstop_y false
#define min_software_endstop_z false
#define max_software_endstop_x true
#define max_software_endstop_y true
#define max_software_endstop_z true
#define ENDSTOP_X_BACK_MOVE 5
#define ENDSTOP_Y_BACK_MOVE 5
#define ENDSTOP_Z_BACK_MOVE 2
#define ENDSTOP_X_RETEST_REDUCTION_FACTOR 3
#define ENDSTOP_Y_RETEST_REDUCTION_FACTOR 3
#define ENDSTOP_Z_RETEST_REDUCTION_FACTOR 3
#define ENDSTOP_X_BACK_ON_HOME 1
#define ENDSTOP_Y_BACK_ON_HOME 1
#define ENDSTOP_Z_BACK_ON_HOME 0
#define ALWAYS_CHECK_ENDSTOPS 1
#define X_ENABLE_ON 0
#define Y_ENABLE_ON 0
#define Z_ENABLE_ON 0
#define DISABLE_X 0
#define DISABLE_Y 0
#define DISABLE_Z 0
#define DISABLE_E 0
#define INVERT_X_DIR 0
#define INVERT_Y_DIR 0
#define INVERT_Z_DIR 0
#define X_HOME_DIR -1
#define Y_HOME_DIR -1
#define Z_HOME_DIR -1
#define X_MAX_LENGTH 300
#define Y_MAX_LENGTH 300
#define Z_MAX_LENGTH 300
#define X_MIN_POS 0
#define Y_MIN_POS 0
#define Z_MIN_POS 0
#define DISTORTION_CORRECTION 0
#define DISTORTION_CORRECTION_POINTS 5
#define DISTORTION_CORRECTION_R 100
#define DISTORTION_PERMANENT 1
#define DISTORTION_UPDATE_FREQUENCY 15
#define DISTORTION_START_DEGRADE 0.5
#define DISTORTION_END_HEIGHT 1
#define DISTORTION_EXTRAPOLATE_CORNERS 0
#define DISTORTION_XMIN 10
#define DISTORTION_YMIN 10
#define DISTORTION_XMAX 190
#define DISTORTION_YMAX 190
#define FEATURE_BABYSTEPPING 1
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

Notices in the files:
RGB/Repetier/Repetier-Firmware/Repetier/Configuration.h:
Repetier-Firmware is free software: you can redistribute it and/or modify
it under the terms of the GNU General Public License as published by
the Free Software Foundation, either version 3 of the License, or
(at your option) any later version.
